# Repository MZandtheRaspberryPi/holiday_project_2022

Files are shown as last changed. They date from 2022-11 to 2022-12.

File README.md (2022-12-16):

# holiday_project_2022

A group of friends got together around the holidays in 2022 to build a fun electronics project in 4 weeks. We decided to build a bat that had some RGB lights, some ultrasound sensors, and a oled for a face.  

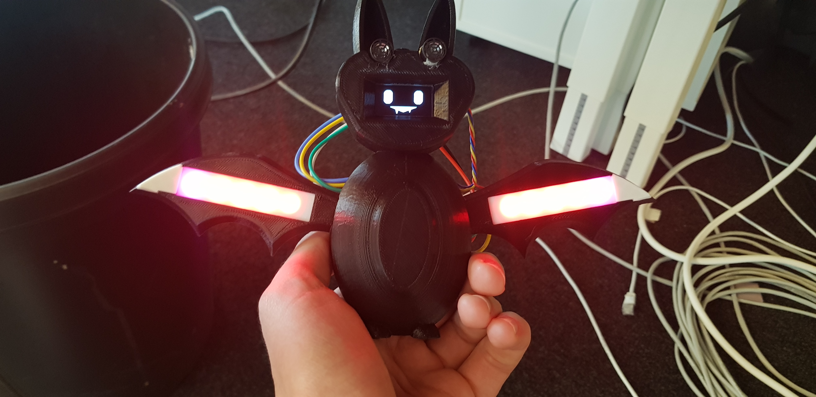
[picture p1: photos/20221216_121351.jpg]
profile_pic

the_wave

This involved designing the bat model and 3d-printing it, working on a software package to drive all the electronics and figure out when something was in front of the bat, and desiging hardware and a PCB to make connecting the electronics easy. You can find more details on each of these in the subfolders design, hardware, and firmware.  

Here are all the parts:  
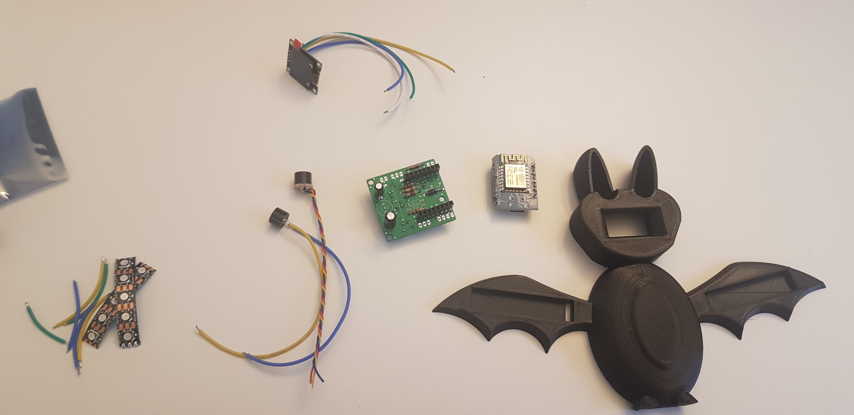
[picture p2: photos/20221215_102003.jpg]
components


We had a pizza party and built 5 of them:
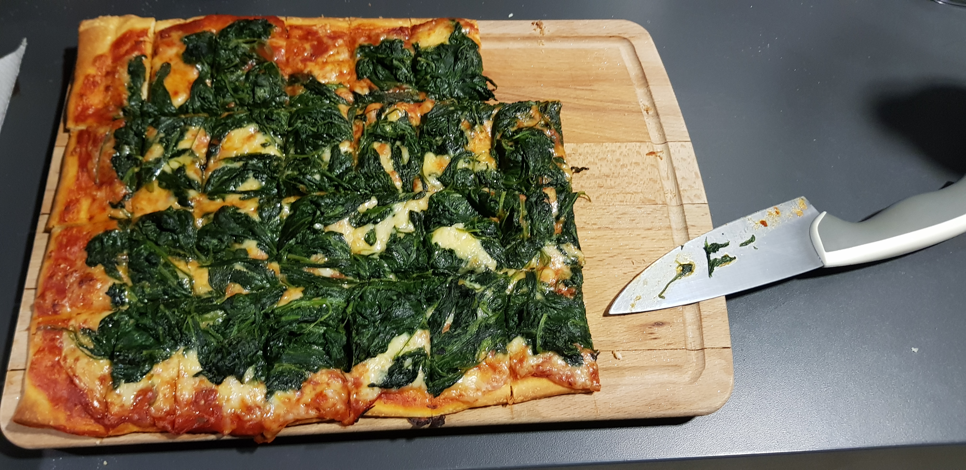
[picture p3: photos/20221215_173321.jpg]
pizza

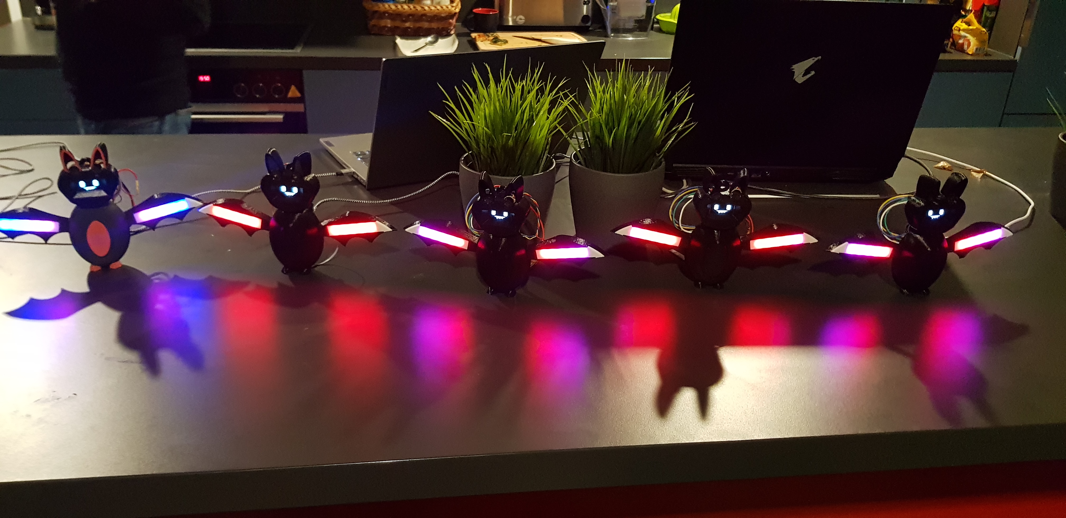
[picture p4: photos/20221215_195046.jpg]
all5


Heres what the back looks like assembled:
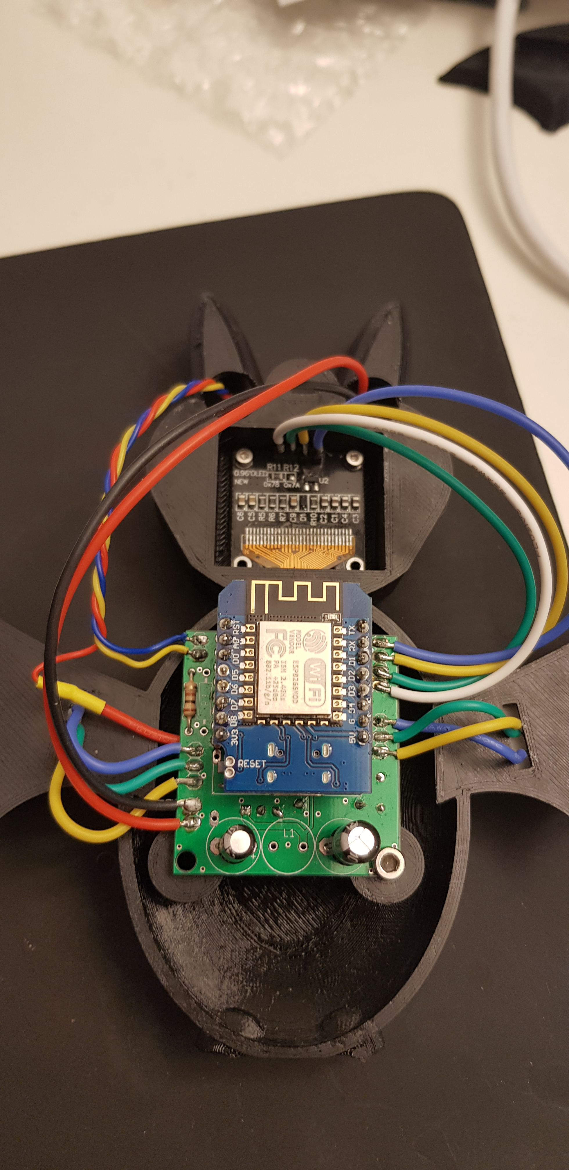
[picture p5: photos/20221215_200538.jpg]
back


This is what the bat is seeing, ie the signal it is sampling and getting from its transducer which is listening:
signal

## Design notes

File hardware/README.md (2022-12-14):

# Hardware

We first brainstormed what components we needed. We wanted to visualize the face, and were deciding between LED Matrix and a screen. We went for an OLED Screen to have better resolution for expressions and animations. We also wanted lights in the wings, and quickly decided on RGB Addressable LEDs. We also wanted ultrasound sensors, and decided eventually on a transducer and complementary circuit.  

From there, it made sense to make a custom PCB to bring it all together. We designed and got the order out quickly, to accomodate shipping times from China. We used only through-hole components to make it easier to solder. You can find a list of components in the BOM.xls file in the repo. If you wanted to order your own, you can find the CAM zipped file in the CAM folder, and can upload that to most fabrication sites.  

An assembly plan is included here. Some of the components were unnescessary, and so we crossed those off in red in the images:  
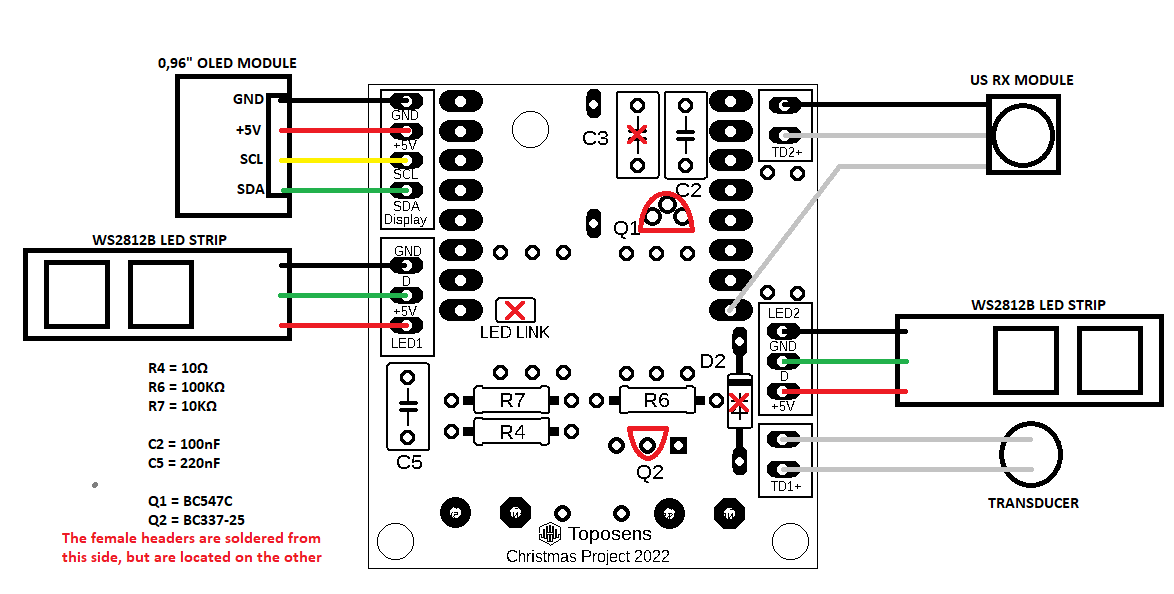
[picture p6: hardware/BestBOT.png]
assembly bottom
  

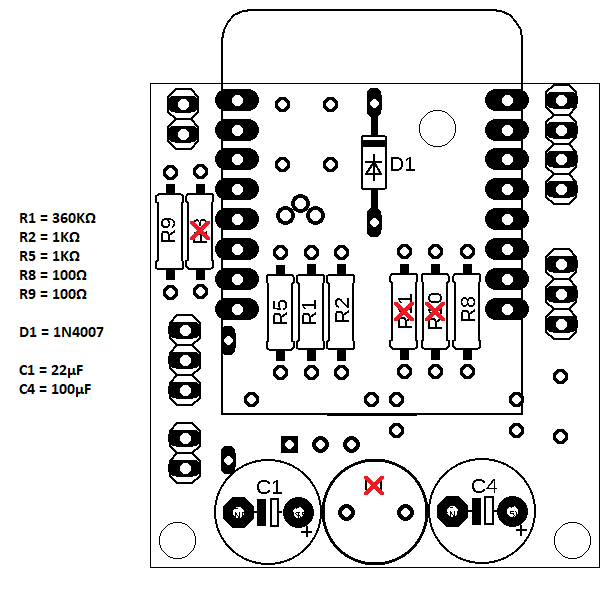
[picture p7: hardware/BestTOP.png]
assembly top


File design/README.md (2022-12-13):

# Design

For the design of this project, we had to make a 3d Model that would fit all of our components. We wanted something cute too.

We did an initial drawing and some browing of inspiration and settled on a cartoonish theme.

From here, we started modelling components in Fusion 360. We did an iterative process, modelling each component like the wing and then printing it to get a feel for how big and how components would fit into it.

You can see the CAD files here, and heres an example screenshot of how they fit together:  
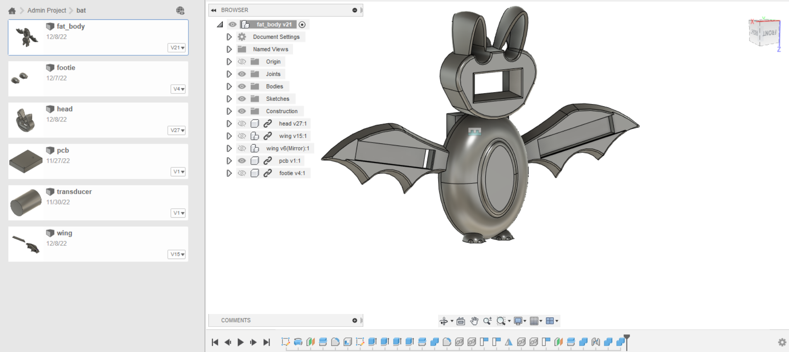
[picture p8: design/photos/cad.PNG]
cad
  

Also included is an STL file of the components joined together that is ready to print, and STL files for the sliders on each wing. We printed the body in Black PLA+ with tree supports, and we printed the sliders in White PLA without supports. We found white pla worked best to diffuse the LEDS in the wings.

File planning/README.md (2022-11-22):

# Planning

This is a project that a group of friends are taking on towards the holidays in 2022. We thought it would be fun to build a project together involving electronics and a little coding.  

First, we need to decide on a project idea and requirements. We will try and keep it relatively small, quick, and cheap. Then we will plan out the hardware, software, and design. We will make a prototype and do a proof of concept. Then we will order components for everyone in the group and build it all together.

## First Meeting Agenda
* Introduce Project
* Timeline
* Sub-groups
* Brainstorming
* Technology brainstorming

## Timeline
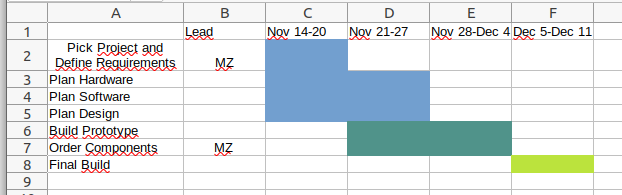
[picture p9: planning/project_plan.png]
gantt_chart


## Voting Results
The bat ornament won, we will make that!
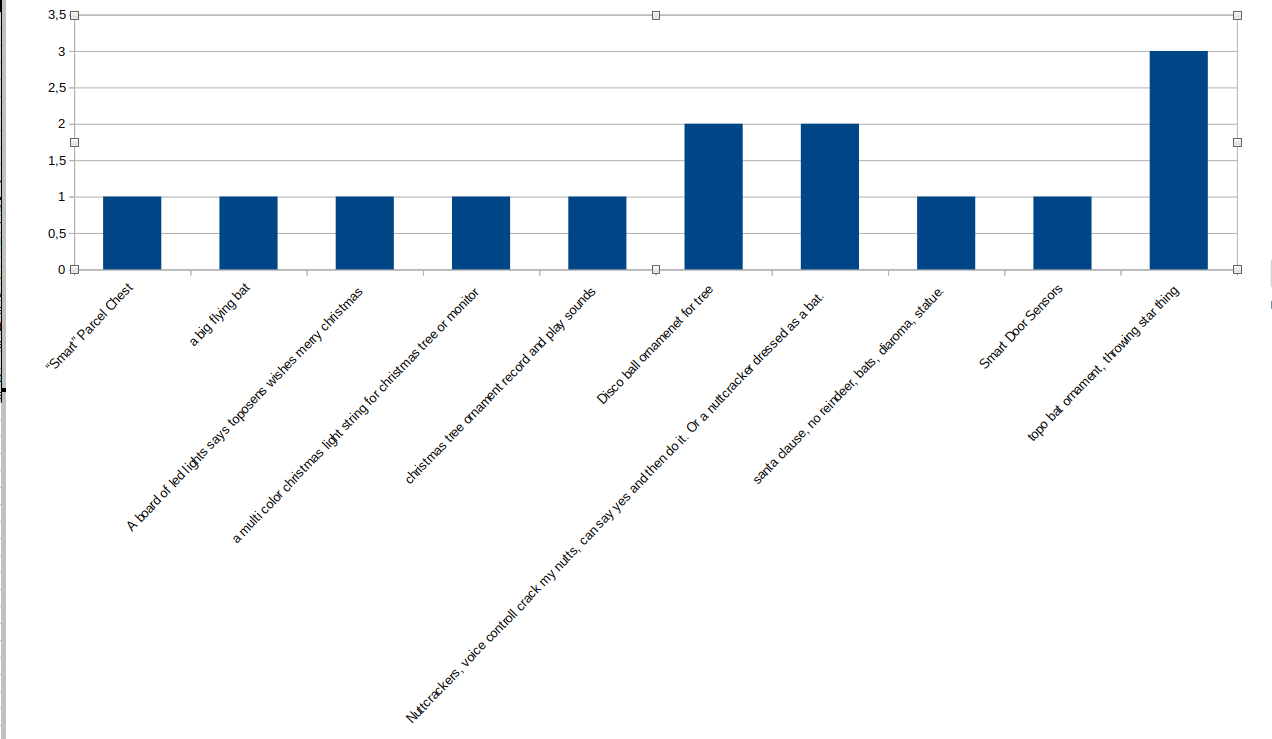
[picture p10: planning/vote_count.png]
voting_results


## feature definition
We met and decided what exactly we will support. We will have a bat, in 3d, with an oled screen for a face that will move and be animated. It will also have ultrasonic sensors in its ears that will let it react to when something is in front of it. It will also have RGB LEDs on its wings, addressable, that will react and animate. It will not be battery powered, it will have a usb cable running from it.

It will look pretty, and be selectively painted. It should have hooks to hang on a christmas tree, or it could stand, or it could slot into a monitor.

## components
* OLED Screen
* 10 Addressable RGB Leds
* ESP 82 66
* Ultrasonic sensor circuit
* USB Cable
* Paint
* 3d Printed Plastic
* Perfboard

## Sub-groups
### Hardware
This group will plan out how to accomplish the requirements from a hardware perspective. This may include identifying components to use and making a schematic.
### Software
This group will plan out how to accomplish the requirements from a software perspective. How do we upload the code, what libraries will we use, how will we structure the code, and how can individuals customize it.
### Design
This group will plan out what the project will look like, and do any CAD nescessary. This may involve making a 3d model and printing it and ensuring fit.
### Prototypers
This group will take the work from the hardware, software, and design groups and make sure it all fits together, building an initial model of the project and ensuring any errors are corrected. This is a nescessary precursor to the group build.

## Final Build
This will involve everyone, we will all get together and everyone will put together and customize their own project.

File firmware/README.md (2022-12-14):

# Firmware

This project's codebase is written in C++. It uses Platform IO to structure, compile, and upload the project, which is similar to Arduino but with some more professional features.

## Uploading the Firmware
Lets say you have a blank ESP and want to upload the code for this project to it.

### Installing VS Code
First, install VS Code. For example, you can download it [here](https://code.visualstudio.com/download).

### Installing GIT
We will need GIT installed to download the code for our project. You can install it [here](https://git-scm.com/download/win) on windows.

### Cloning the Project
You will need to clone the project using git, which means you will copy the code to a place on your computer.

Open Git Bash, which you should have installed when you installed git, and you will see a terminal. Enter the below command into the terminal, and run it by hitting enter. It will clone the code to a new folder. It should look like the below when you are done:  
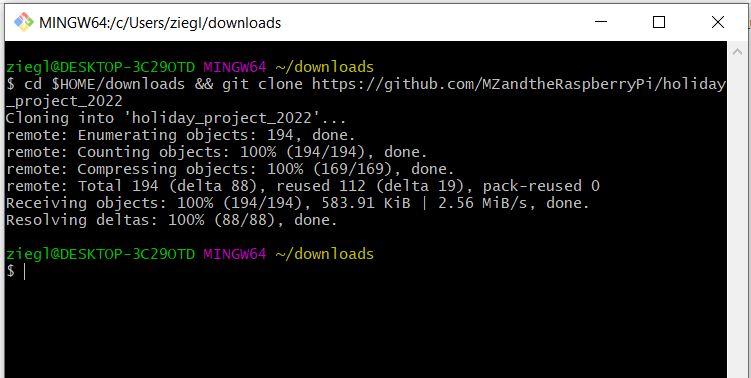
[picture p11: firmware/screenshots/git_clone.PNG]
git clone
  

### Opening the Repo in VS Code
Open VS Code, and click the file menu in the top left and hit open. Browse to your downloads folder, where we saved the code we downloaded.  

From there, open the folder. You should see something like the below:  
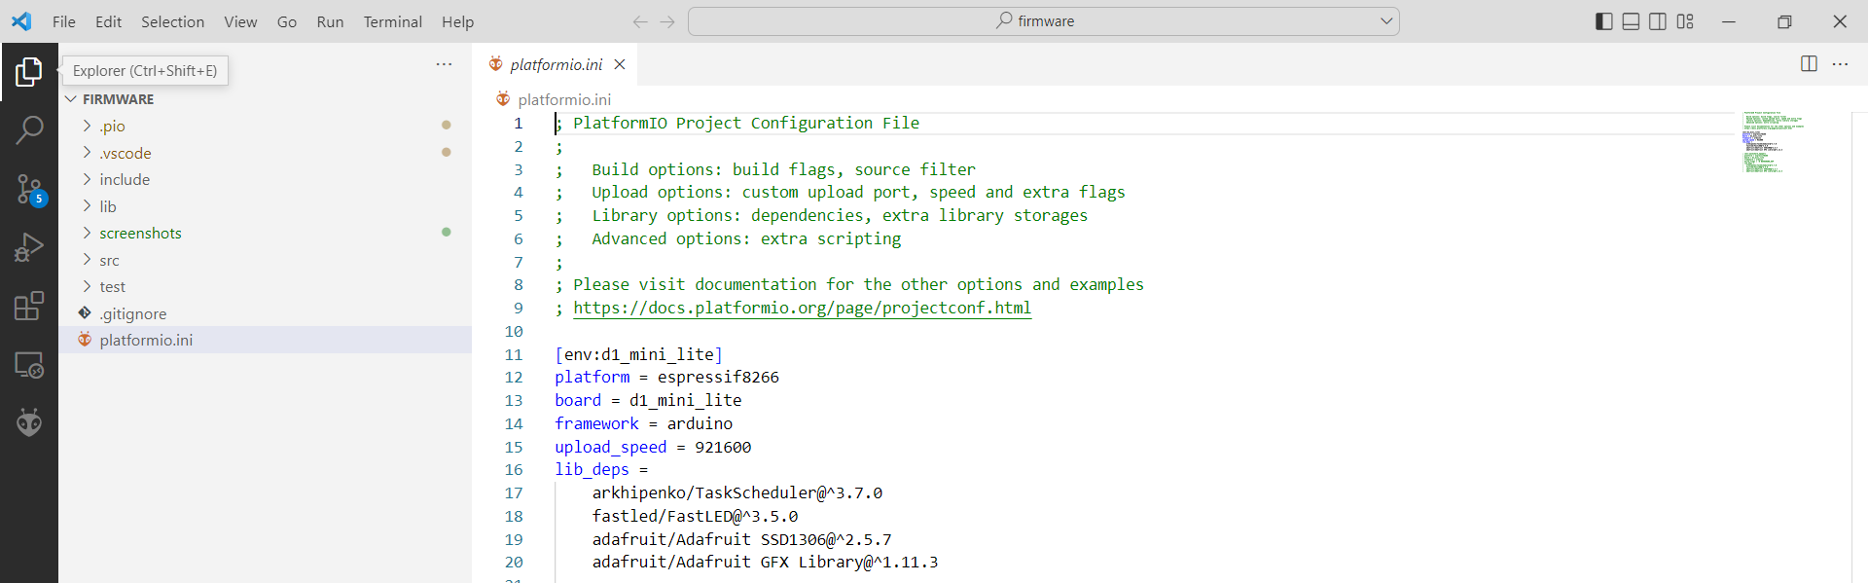
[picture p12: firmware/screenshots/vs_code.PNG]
vs_code
  

### Installing Platform IO
Platform IO is an extension for VS Code. In the dark grey menu on the left, click the boxes, and search for platform io and install it.

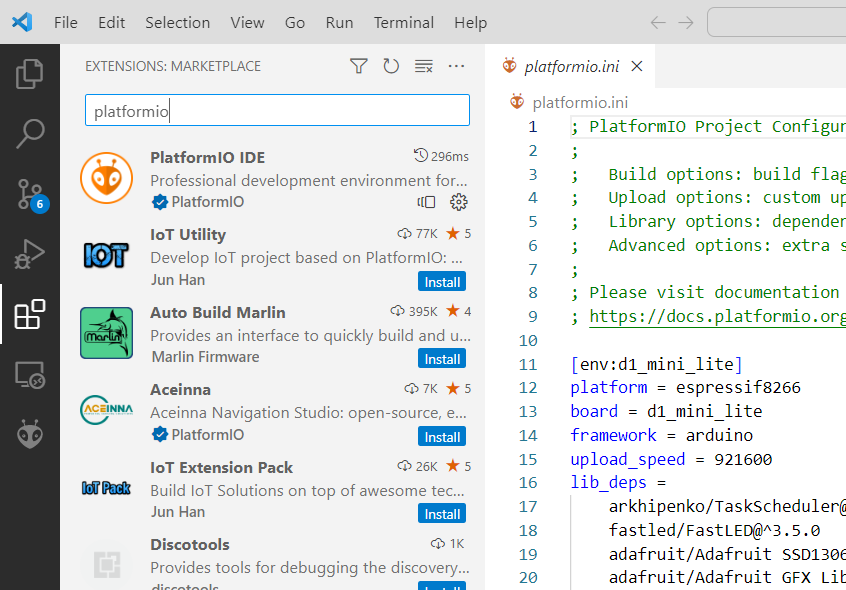
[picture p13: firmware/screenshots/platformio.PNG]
platformio
  

### Opening the Project with Platform IO
From here, relaunch VS Code. When you do, platform IO may show you a menu like the below. Click open a project, and open the firmware folder in the repo we cloned:  

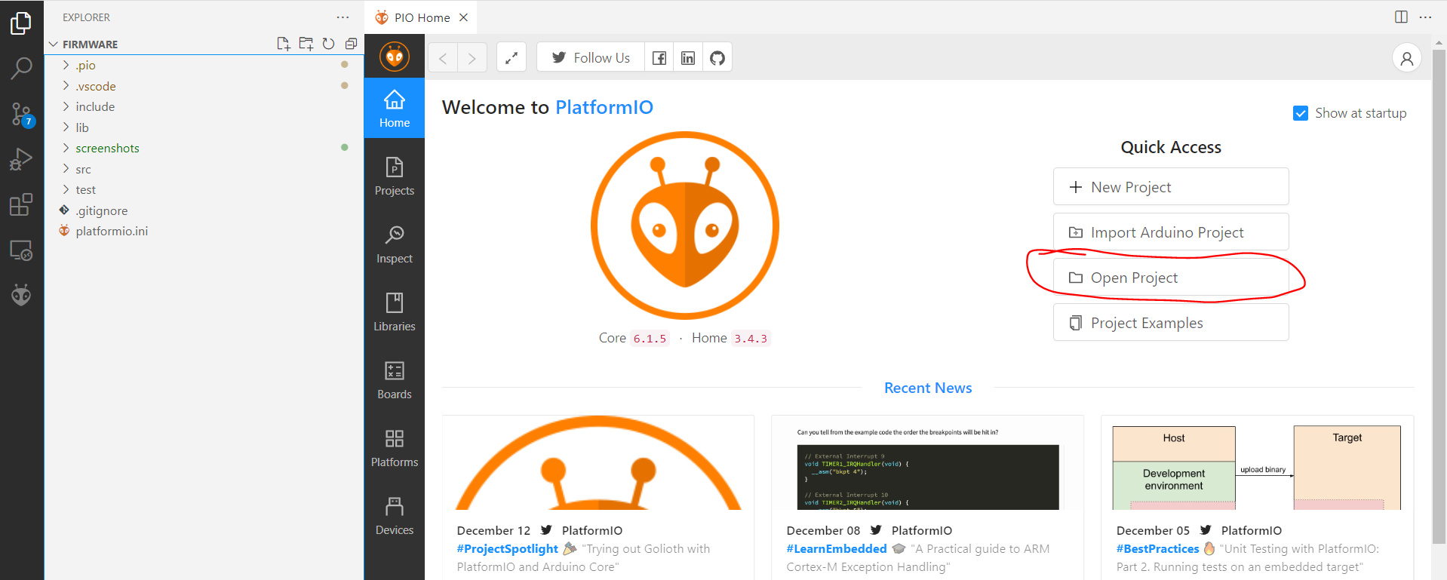
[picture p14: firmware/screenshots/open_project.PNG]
open in platformio
  
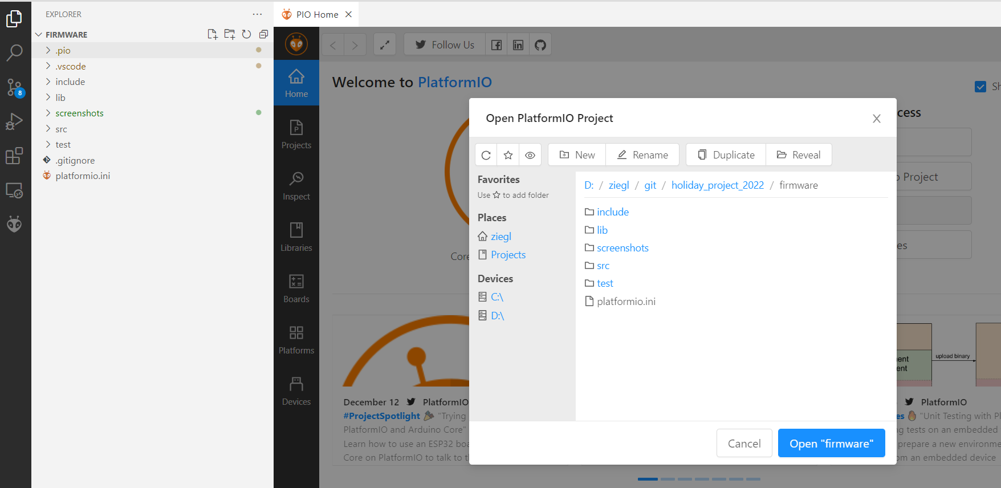
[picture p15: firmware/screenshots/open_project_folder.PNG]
open in platformio with browser
  

### Compile the code and Upload
Select in the bottom the ESP we have, and from there hit the green checkbox to compile. If that goes well, then hit the upload button, the arrow.  

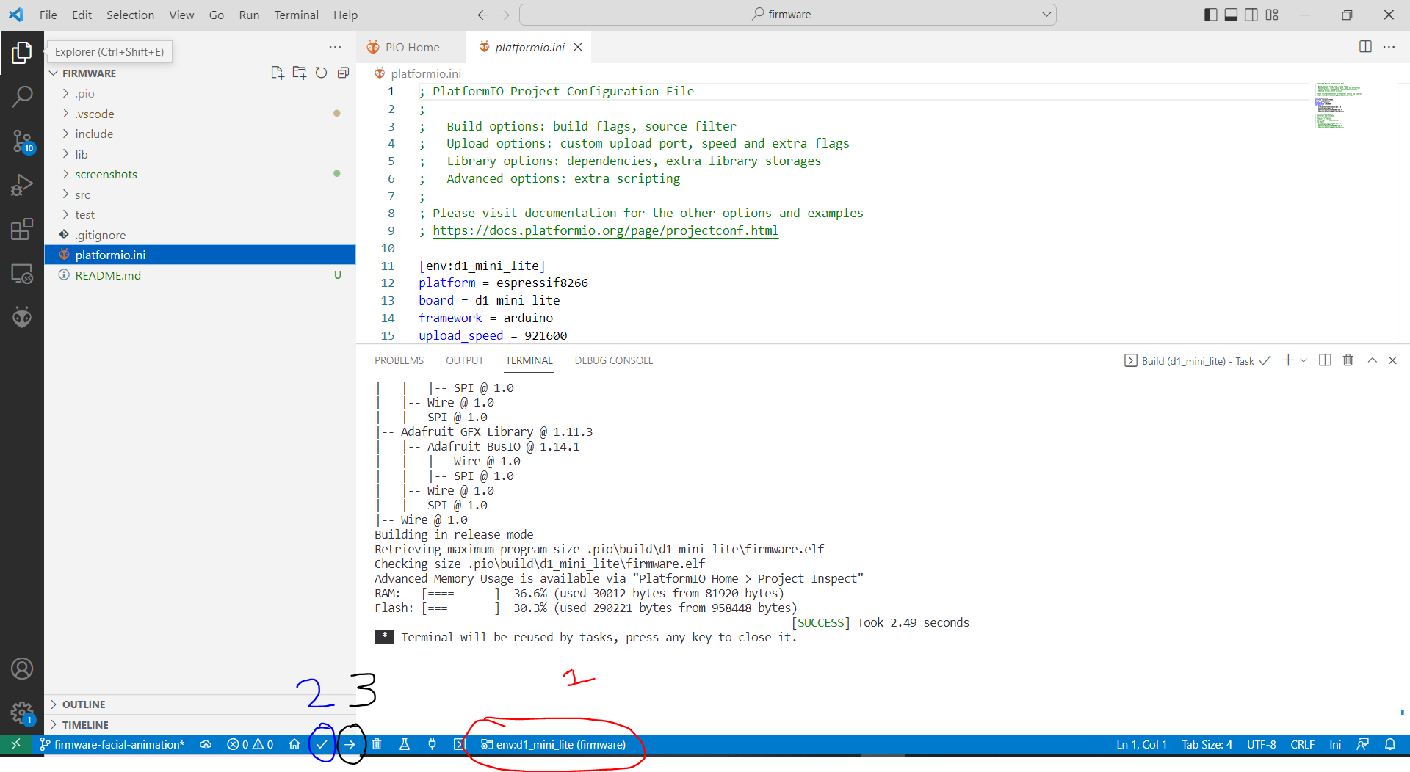
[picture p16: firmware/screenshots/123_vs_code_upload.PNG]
compile and upload


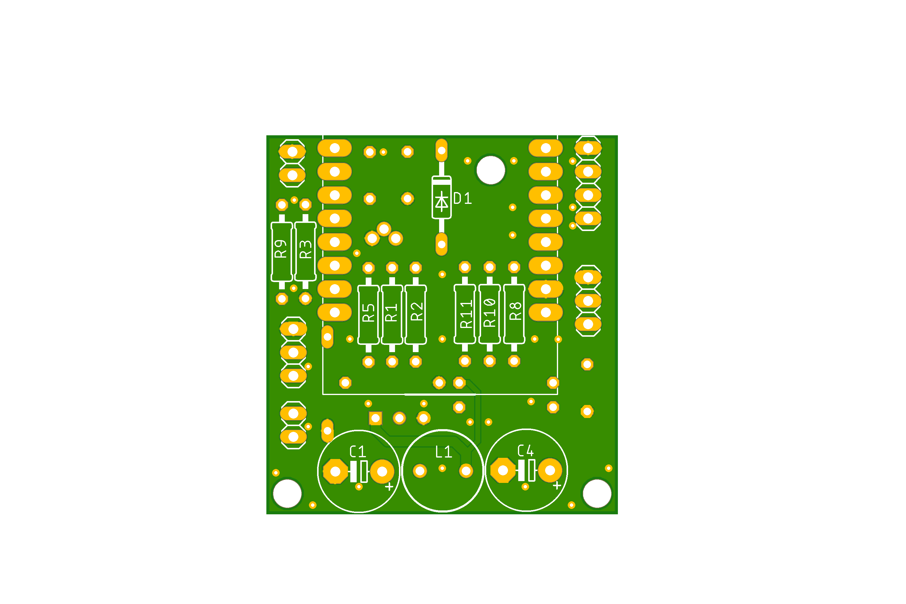
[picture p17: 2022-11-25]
hardware/minibat top.png

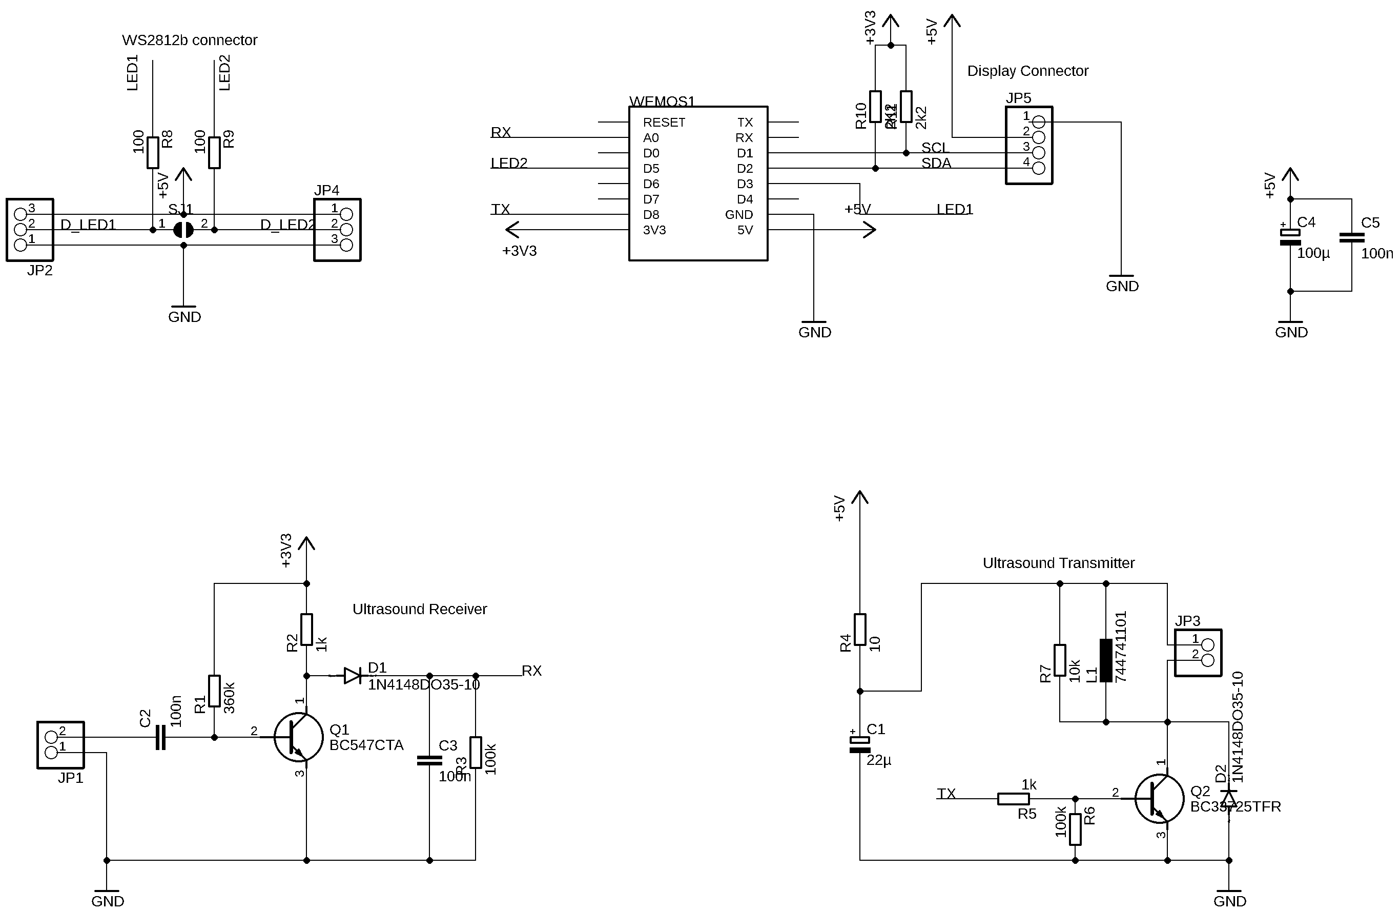
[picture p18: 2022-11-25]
hardware/Schematic.png

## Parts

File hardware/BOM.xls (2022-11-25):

Part | Value | Package | Description
C1 | 22µ | E5-8,5 | Electrolytic Capacitor
C2 | 100n | C050-035X075 | Film Capacitor
C3 | 100n | C050-035X075 | Film Capacitor
C4 | 100µ | E5-8,5 | Electrolytic Capacitor
C5 | 100n | C050-035X075 | Film Capacitor
D1 | 1N4148 | DO35-10 | Signal Diode
D2* | ZPD18 | DO35-10 | 18V Zener Diode
L1* | WE744741101 | 6000-XXXX-RC | Power Inductor
Q1 | BC547CTA | TO-92 | NPN Transistor, 100mA , 45V
Q2 | BC337-40 | TO-92 | NPN Transistor, 800 mA, 50 V
R1 | 360k | 0207/10 | RESISTOR, 250mW
R2 | 1k | 0207/10 | RESISTOR, 250mW
R3 | 100k | 0207/10 | RESISTOR, 250mW
R4 | 10R | 0207/10 | RESISTOR, 250mW
R5 | 1k | 0207/10 | RESISTOR, 250mW
R6 | 100k | 0207/10 | RESISTOR, 250mW
R7 | 10k | 0207/10 | RESISTOR, 250mW
R8 | 100R | 0207/10 | RESISTOR, 250mW
R9 | 100R | 0207/10 | RESISTOR, 250mW
R10 | 2K2 | 0207/10 | RESISTOR, 250mW
R11 | 2k2 | 0207/10 | RESISTOR, 250mW
WEMOS1 |  | WEMOS-D1-MINI | ESP8266 Module
 |  |  |  | *Optional - For HP Version

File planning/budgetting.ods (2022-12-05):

 |  | people | 10 | price/person | 12,708
component | price
12 x Esp8266 & oled screens | 45,02
WS812B led strip 1m | 12,67
black pla+ 1 kilogram | 17,64
5 usb c cables | 6,75
custom pcbs from china | 25,00
components for ultrasound circuit | 20,00
total | 127,08

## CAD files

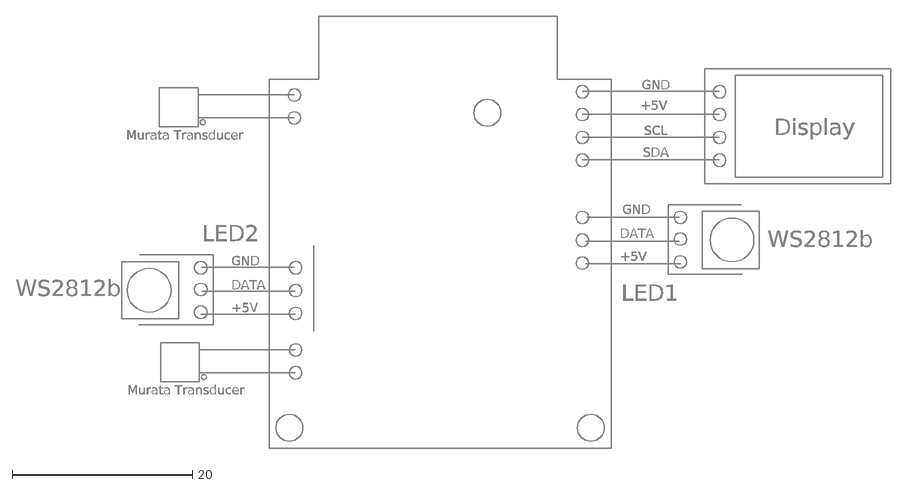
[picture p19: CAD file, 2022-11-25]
hardware/minibat.dxf
LED2
GND
DATA
+5V
WS2812b
Murata Transducer
LED1
SCL
SDA
Display

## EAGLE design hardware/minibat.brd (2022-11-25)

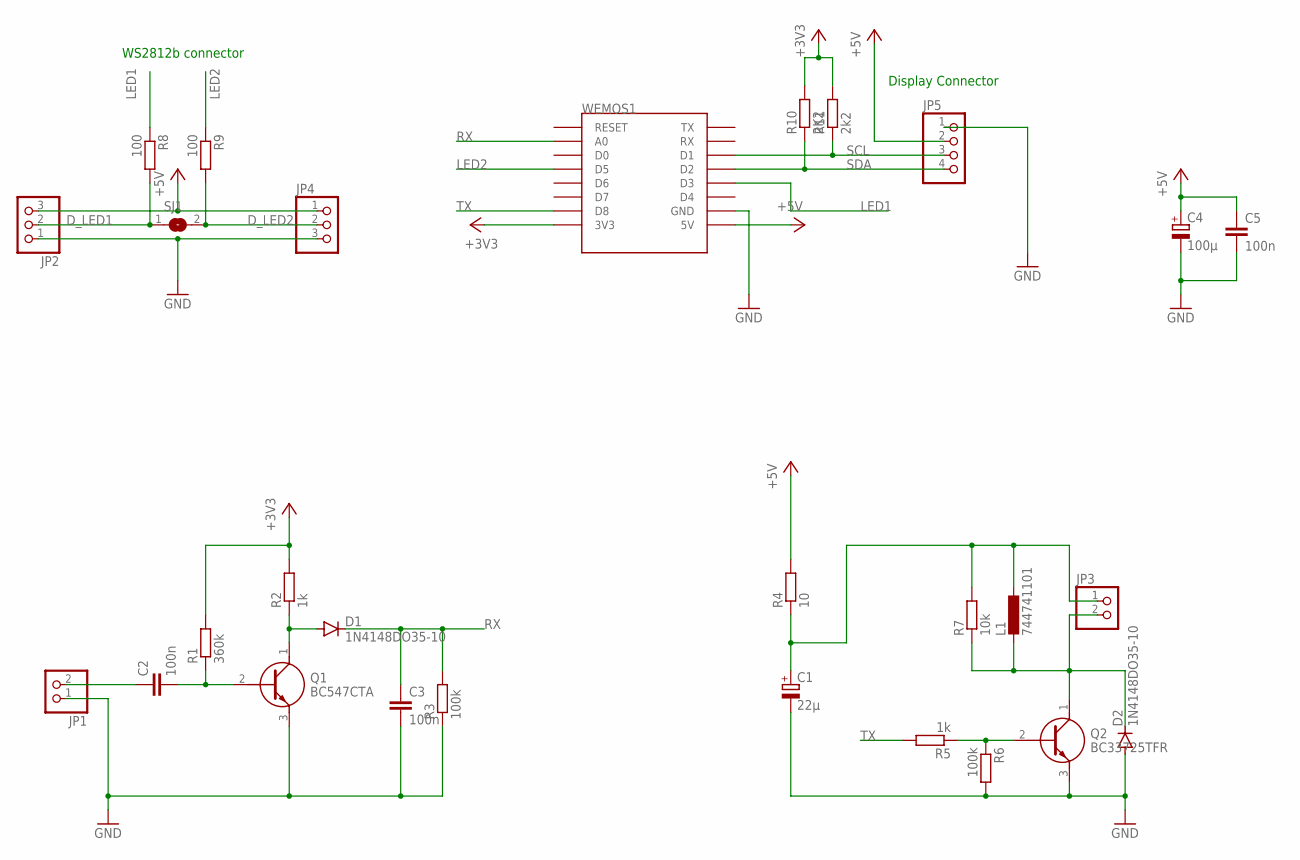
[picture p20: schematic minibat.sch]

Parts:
C1: 22µ; E5-8,5
C2, C3, C5: 100n; C050-035X075
C4: 100µ; E5-8,5
D1, D2: 1N4148DO35-10; DO35-10
JP1, JP3: PINHD-1X2; 1X02
JP2, JP4: PINHD-1X3; 1X03
JP5: PINHD-1X4; 1X04
L1: 744741101; 6000-XXXX-RC
Q1: BC547CTA; MC79L15ACPG
Q2: BC33725TFR
R1: 360k; 0207/10
R2, R5: 1k; 0207/10
R3, R6: 100k; 0207/10
R4: 10; 0207/10
R7: 10k; 0207/10
R8, R9: 100; 0207/10
R10: 2K2; 0207/10
R11: 2k2; 0207/10
SJ1: SJ
WEMOS1: WEMOS-D1-MINI

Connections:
+3V3: R1.2, R2.2, R10.2, R11.2, WEMOS1.3V3
+5V: C4.+, C5.1, JP2.3, JP4.1, JP5.2, R4.2, WEMOS1.5V
D_LED1: JP2.2, R8.2, SJ1.1
D_LED2: JP4.2, R9.2, SJ1.2
GND: C1.-, C3.2, C4.-, C5.2, D2.A, JP1.1, JP2.1, JP4.3, JP5.1, Q1.3 (E), Q2.3 (E), R3.1, R6.2, WEMOS1.GND
LED1: R8.1, WEMOS1.D3
LED2: R9.1, WEMOS1.D5
unnamed: C2.1, JP1.2
unnamed: D1.A, Q1.1 (C), R2.1
unnamed: C2.2, Q1.2 (B), R1.1
unnamed: C1.+, JP3.1, L1.1, R4.1, R7.2
unnamed: D2.C, JP3.2, L1.2, Q2.1 (C), R7.1
unnamed: Q2.2 (B), R5.1, R6.1
RX: C3.1, D1.C, R3.2, WEMOS1.A0
SCL: JP5.3, R11.1, WEMOS1.D1
SDA: JP5.4, R10.1, WEMOS1.D2
TX: R5.2, WEMOS1.D8

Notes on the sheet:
Display Connector
WS2812b connector

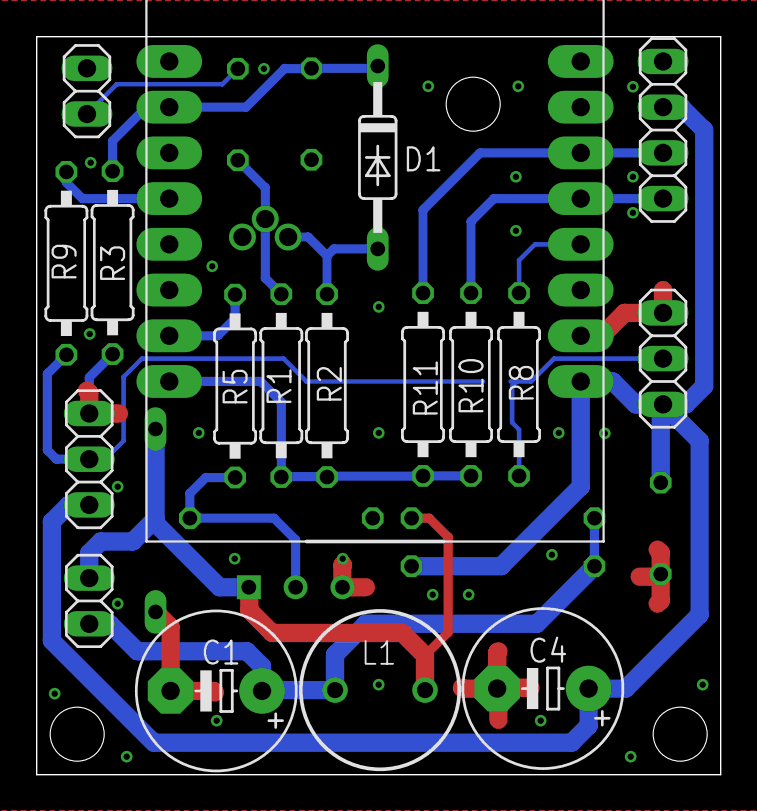
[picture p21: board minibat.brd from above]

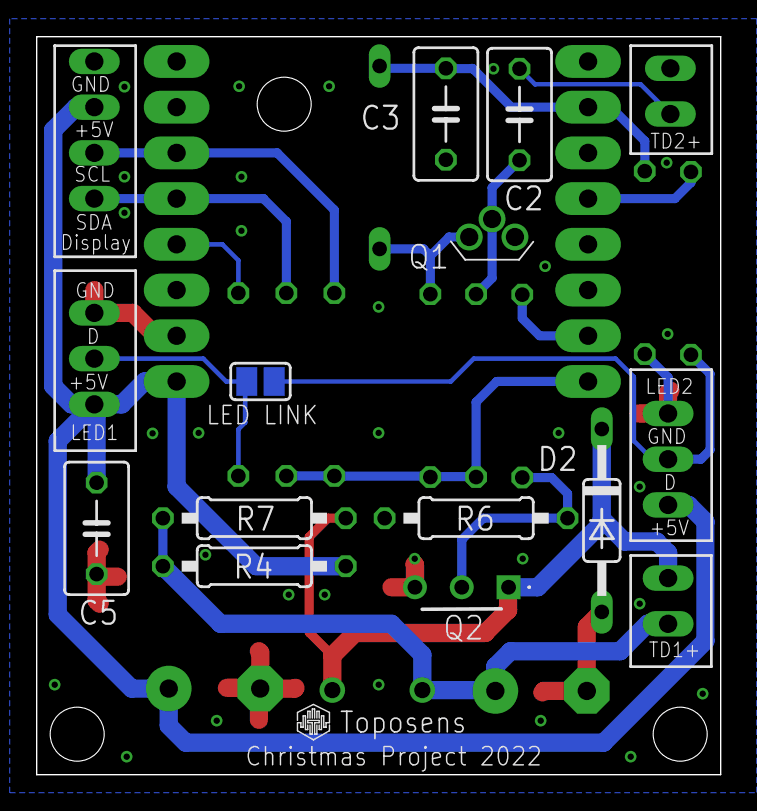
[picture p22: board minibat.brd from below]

Board: 2 copper layers, 38.0 x 41.0 mm, 28 parts (10 on the bottom side), 17 nets.

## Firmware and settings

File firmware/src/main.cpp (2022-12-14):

#include <Arduino.h>
#include <TaskScheduler.h>

#include "led.h"
#include "oled.h"
#include "transducer.h"
#include "pins.h"

Scheduler runner;
Task Task_LED_WS2812(TASK_LED_INTERVAL, TASK_FOREVER, &Task_LED_Periodic, &runner, false, &Task_LED_Setup);
Task Task_OLED(TASK_OLED_INTERVAL, TASK_FOREVER, &Task_OLED_Periodic, &runner, false, &Task_OLED_Setup);
Task Task_Transducer(TASK_TRANSDUCER_INTERVAL, TASK_FOREVER, &Task_Transducer_Periodic, &runner, false, &Task_Transducer_Setup);

void setup() {
  Serial.begin(9600);

  Task_LED_WS2812.enable();
  Task_OLED.enable();
  Task_Transducer.enable();

  runner.startNow();
}

void loop() {
  runner.execute(); // It is necessary to run the runner on each loop
}

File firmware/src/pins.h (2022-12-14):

#ifndef PINS_H
#define PINS_H

#include <Arduino.h>

// Transducer
#define PIN_PWM D8
#define PIN_ADC A0

// OLED
#ifdef WAVESHARE_ESP
#define CUSTOM_I2C_PINS
#define PIN_WIRE_SDA_CUSTOM (13)
#define PIN_WIRE_SCL_CUSTOM (14)
#endif

// WS2812
#define PIN_WS2812_L   D5
#define PIN_WS2812_R   D3

#endif // PINS_H

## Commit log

2022-11-16 initial planning commit
    [brainstorming.ods, gantt_chart.ods]
2022-11-16 adding ideas and such
    [brainstorming.ods, gantt_chart.ods]
2022-11-18 updating brainstorm spreadsheet
    [brainstorming.ods]
2022-11-23 adding budget
    [budgetting.ods]
2022-11-25 adding hardware, updating budget
    [BOM.xls, budgetting.ods, minibat.brd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]
2022-12-05 updating budget
    [budgetting.ods]
2022-12-05 add second board config
2022-12-10 add led modes and use d1 mini pins
2022-12-10 add display of adc values
2022-12-12 add adc plot mode
2022-12-13 adding cad
